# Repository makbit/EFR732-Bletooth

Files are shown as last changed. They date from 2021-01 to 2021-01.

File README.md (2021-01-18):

# EFR732-Bluetooth
EFR732 - is a multi-protocol radio board based on the [EFR32MG1P732F256GM32 @40MHz MCU](https://www.silabs.com/wireless/zigbee/efr32mg1-series-1-socs/device.efr32mg1p732f256gm32) from the SiliconLabs in the 5x5mm QFN32 package. Now this MCU is announced as deprecated. :disappointed:

This MCU supports:
* Bluetooth Smart (BLE),
* ZigBee,
* Thread,
* Proprietary protocols.

Maximum TX Power is: 2.4 GHz @ 19.5 dBm, Antenna in the SMA connector adds +3dBm.
This MCU integrate a 512kB serial flash in the package.

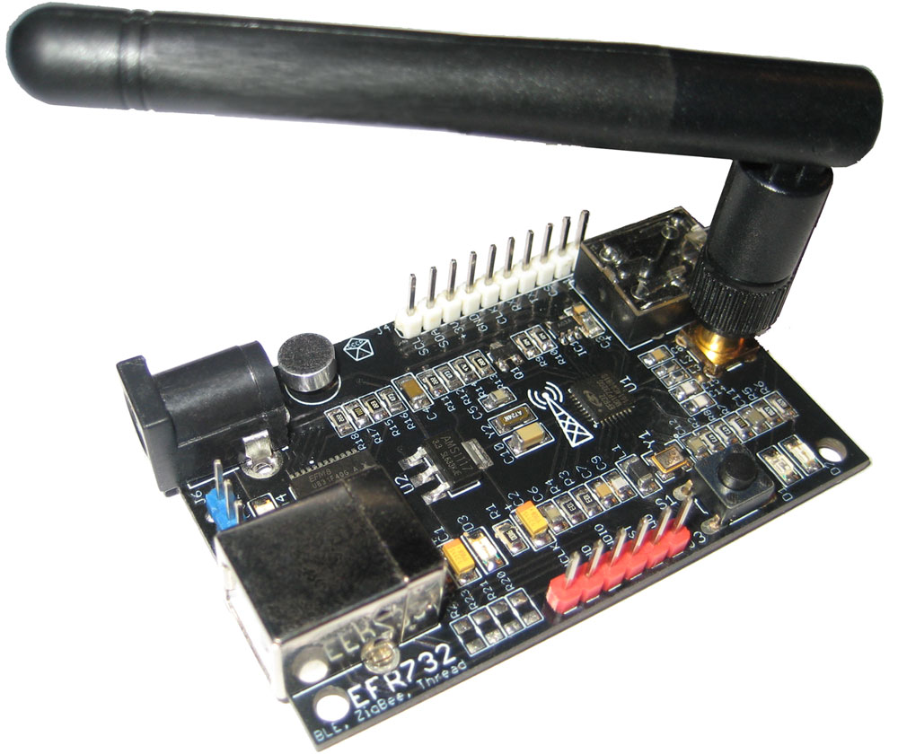
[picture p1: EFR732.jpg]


### Key features:
 - The board has JTAG/SWD pins compatible with the J-Link debug adapter (PF0 - SWCLK, PF1 - SWDIO, PF2 - SWO).
 - The on-board microphone with the amplifier is connected to the MCU ADC port (PB13).
 - The iDAC output is amplified with the LM321 (PB12).
 - There is a USB-to-UART bridge based on the [EFM8UB31F40 MCU](https://www.silabs.com/mcu/8-bit/efm8-universal-bee/device.efm8ub31f40g-qsop24) : P04_TX -> PA1_RX, P05_RX -> PA0_TX. I hope this 8051 MCU can be used as a programmer/debugger someday.
 - Two pins are connected: P03 -> PB11 (clk), P06 -> PD13 (cs). Debug pins are not connected yet.
 - User push-button is connected to PF3.

The [`Hardware`](Hardware) folder contains Eagle CAD 9.0 schematics files. Component library can be found in my repositories.
The board schematics can be found in the[`Hardware/EFR732.png`](Hardware/EFR732.png) file.

### TODO
- [ ] Add firmware folder with examples and some useful stuff.
- [ ] Write USB-to-UART firmware for EFM8.

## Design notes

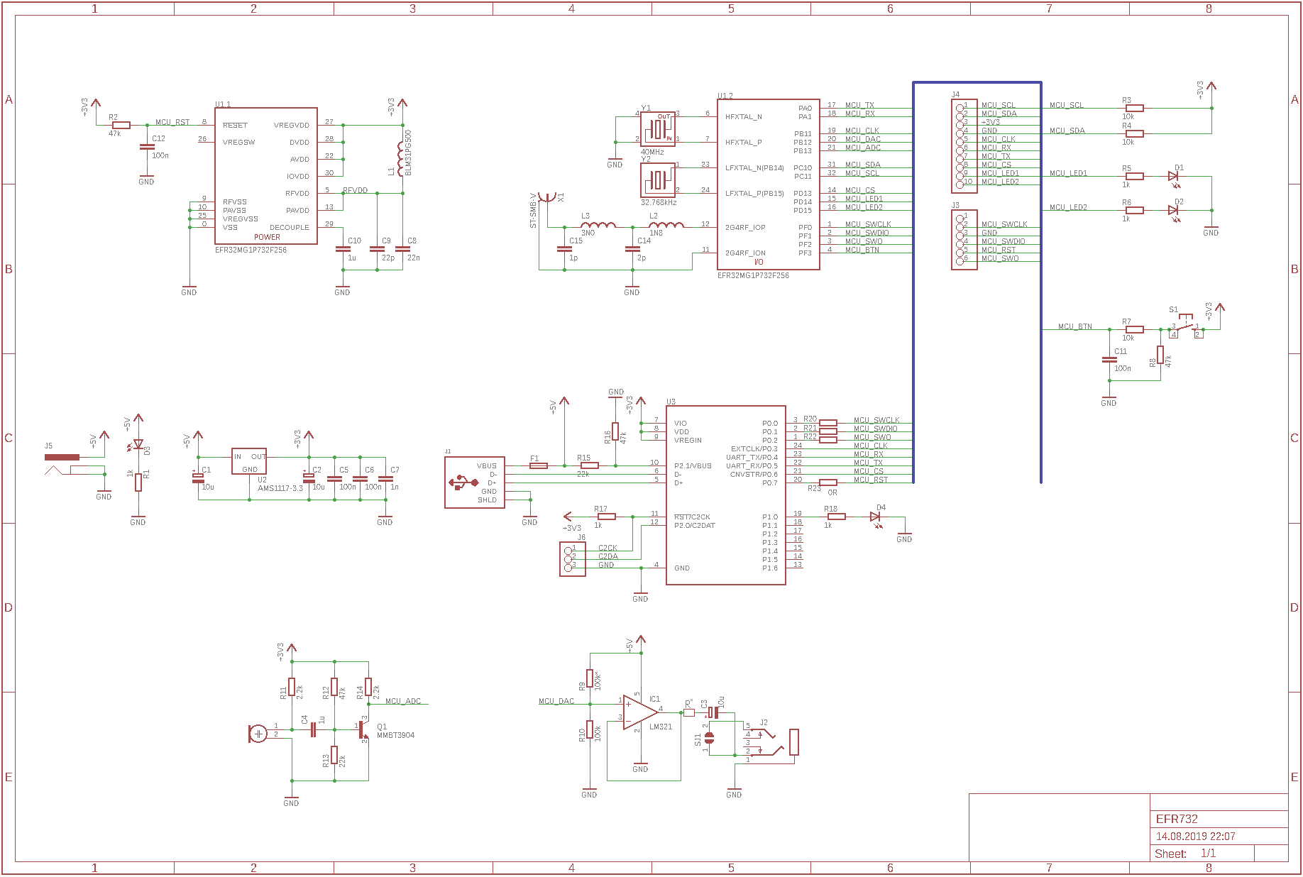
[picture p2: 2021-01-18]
Hardware/EFR732.png

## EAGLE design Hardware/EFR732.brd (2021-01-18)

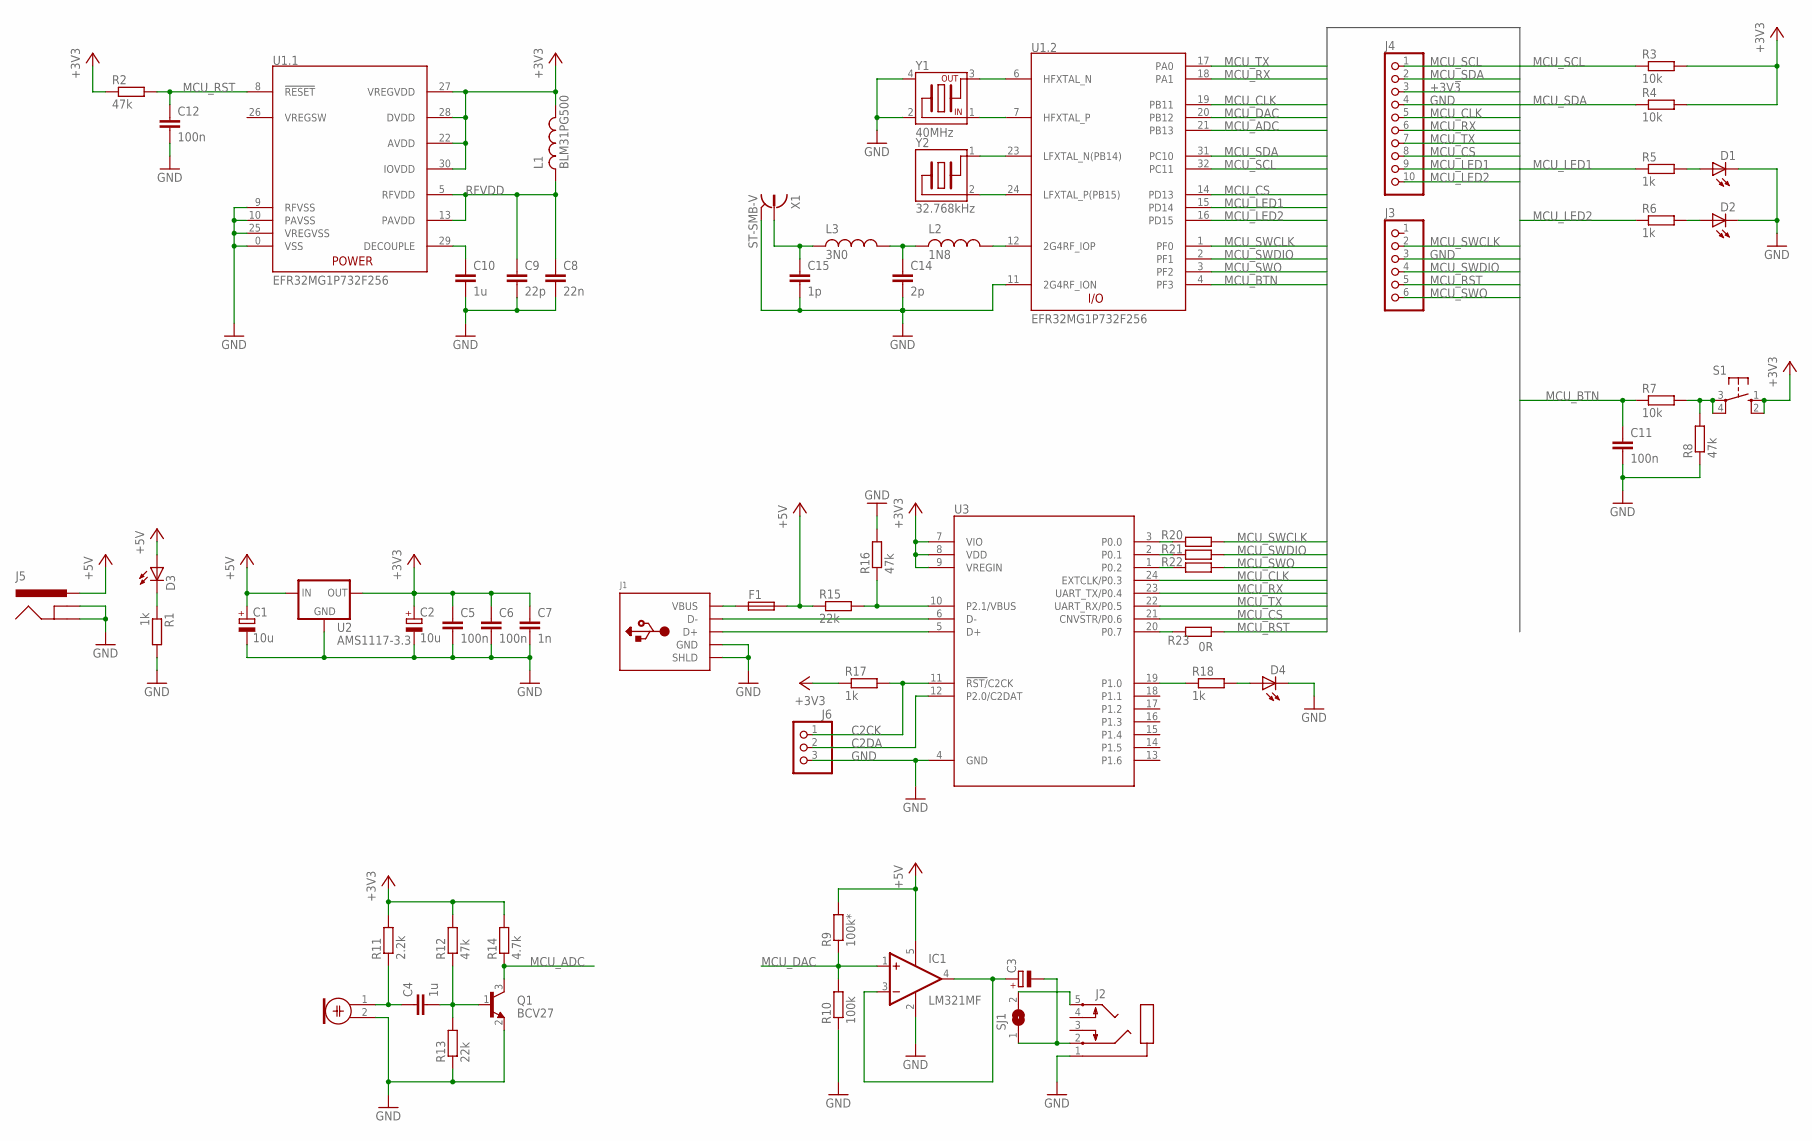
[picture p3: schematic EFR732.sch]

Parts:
C1, C2: 10u; RCL-1206F-POL
C3: CPOL-EU; RCL-1206F-POL
C4, C10: 1u; RCL-1206F
C5, C6, C11, C12: 100n; RCL-0805F
C7: 1n; RCL-0805F
C8: 22n; RCL-0805F
C9: 22p; RCL-0805F
C14: 2p; RCL-0805F
C15: 1p; RCL-0805F
D1, D2, D3, D4: LED1206; LED-1206F
F1: FUSE-NSMF; RCL-1206F
IC1: LM321MF; SOT23-5
J1: USB-TYPE-B; USB-TYPE-B-4P
J2: AUDIO-JACK-3.5MM; AUDIO-PG203J
J3: PINH-1X06
J4: PINH-1X10
J5: POWER_JACK; POWER_JACK_PTH
J6: PINHD-1X3; 1X03
L1: BLM31PG500; RCL-1206F
L2: 1N8; RCL-0603F
L3: 3N0; RCL-0603F
M1: ELECTRET_MICROPHON-WM-62PC/62PK; WM-62PC/62PK
Q1: BCV27; SOT23
R1, R5, R6, R17, R18: 1k; RCL-0805F
R2, R8, R12, R16: 47k; RCL-0805F
R3, R4, R7: 10k; RCL-0805F
R9: 100k*; RCL-0805F
R10: 100k; RCL-0805F
R11: 2.2k; RCL-0805F
R13, R15: 22k; RCL-0805F
R14: 4.7k; RCL-0805F
R20, R21, R22: R-EU0805; RCL-0805F
R23: 0R; RCL-0805F
S1: SWITCH-10-XX; BUTTON-B3F-10XX
SJ1: SJ
U1: EFR32MG1P732F256; QFN32_5X5MM_EFR32MG1
U2: AMS1117-3.3; SOT223
U3: EFM8UB31F40G-QSOP24; QSOP24-3.9X8.65MM
X1: ST-SMB-V
Y1: 40MHz; XTAL-FA-238
Y2: 32.768kHz; XTAL-FC-135

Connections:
+3V3: C2.+, C5.1, C6.1, C7.1, J4.3, L1.2, R2.1, R3.2, R4.2, R11.2, R12.2, R14.2, R17.1, S1.1 (S), S1.2 (S1), U1.22 (AVDD), U1.27 (VREGVDD), U1.28 (DVDD), U1.30 (IOVDD), U2.2 (OUT), U2.4 (OUT), U3.7 (VIO), U3.8 (VDD), U3.9 (VREGIN)
+5V: C1.+, D3.A, F1.2, IC1.5 (V+), J5.PWR, R9.2, R15.1, U2.3 (IN)
C2CK: J6.1, R17.2, U3.11 (!RST/!C2CK)
C2DA: J6.2, U3.12 (P2.0/C2DAT)
GND: C1.-, C2.-, C5.2, C6.2, C7.2, C8.2, C9.2, C10.2, C11.2, C12.2, C14.2, C15.2, D1.C, D2.C, D4.C, IC1.2 (V-), J1.4_GND (GND), J1.M1 (SHLD), J1.M2 (SHLD), J2.1, J3.3, J4.4, J5.GND, J5.GNDBREAK, J6.3, M1.2, Q1.2 (E), R1.2, R8.1, R10.1, R13.1, R16.2, U1.0 (VSS), U1.9 (RFVSS), U1.10 (PAVSS), U1.11 (2G4RF_ION), U1.25 (VREGVSS), U2.1 (GND), U3.4 (GND), X1.2, X1.3 (2), X1.4 (2), X1.5 (2), Y1.2, Y1.4
MCU_ADC: Q1.3 (C), R14.1, U1.21 (PB13)
MCU_BTN: C11.1, R7.1, U1.4 (PF3)
MCU_CLK: J4.5, U1.19 (PB11), U3.24 (EXTCLK/P0.3)
MCU_CS: J4.8, U1.14 (PD13), U3.21 (CNVSTR/P0.6)
MCU_DAC: IC1.1 (+IN), R9.1, R10.2, U1.20 (PB12)
MCU_LED1: J4.9, R5.1, U1.15 (PD14)
MCU_LED2: J4.10, R6.1, U1.16 (PD15)
MCU_RST: C12.1, J3.5, R2.2, R23.2, U1.8 (!RESET)
MCU_RX: J4.6, U1.18 (PA1), U3.23 (UART_TX/P0.4)
MCU_SCL: J4.1, R3.1, U1.32 (PC11)
MCU_SDA: J4.2, R4.1, U1.31 (PC10)
MCU_SWCLK: J3.2, R20.2, U1.1 (PF0)
MCU_SWDIO: J3.4, R21.2, U1.2 (PF1)
MCU_SWO: J3.6, R22.2, U1.3 (PF2)
MCU_TX: J4.7, U1.17 (PA0), U3.22 (UART_RX/P0.5)
unnamed: U1.23 (LFXTAL_N(PB14)), Y2.1 (1.XIN)
unnamed: U1.24 (LFXTAL_P(PB15)), Y2.2 (2.XIN)
unnamed: U1.7 (HFXTAL_P), Y1.1 (X.IN)
unnamed: U1.6 (HFXTAL_N), Y1.3 (X.OUT)
unnamed: F1.1, J1.1_VBUS (VBUS)
unnamed: C14.1, L2.1, L3.2
unnamed: R20.1, U3.3 (P0.0)
unnamed: C15.1, L3.1, X1.1
unnamed: D3.C, R1.1
unnamed: D1.A, R5.2
unnamed: C10.1, U1.29 (DECOUPLE)
unnamed: D2.A, R6.2
unnamed: C3.+, IC1.3 (-IN), IC1.4 (OUT)
unnamed: J2.5, SJ1.2
unnamed: R7.2, R8.2, S1.3, S1.4 (P1)
unnamed: J1.2_DM (D-), U3.6 (D-)
unnamed: J1.3_DP (D+), U3.5 (D+)
unnamed: R21.1, U3.2 (P0.1)
unnamed: R15.2, R16.1, U3.10 (P2.1/VBUS)
unnamed: C4.1, M1.1, R11.1
unnamed: C3.-, J2.2, SJ1.1
unnamed: C4.2, Q1.1 (B), R12.1, R13.2
unnamed: R22.1, U3.1 (P0.2)
unnamed: R18.1, U3.19 (P1.0)
unnamed: D4.A, R18.2
unnamed: R23.1, U3.20 (P0.7)
RFVDD: C8.1, C9.1, L1.1, U1.5 (RFVDD), U1.13 (PAVDD)
RF_IOP: L2.2, U1.12 (2G4RF_IOP)
VREGSW: U1.26 (VREGSW)

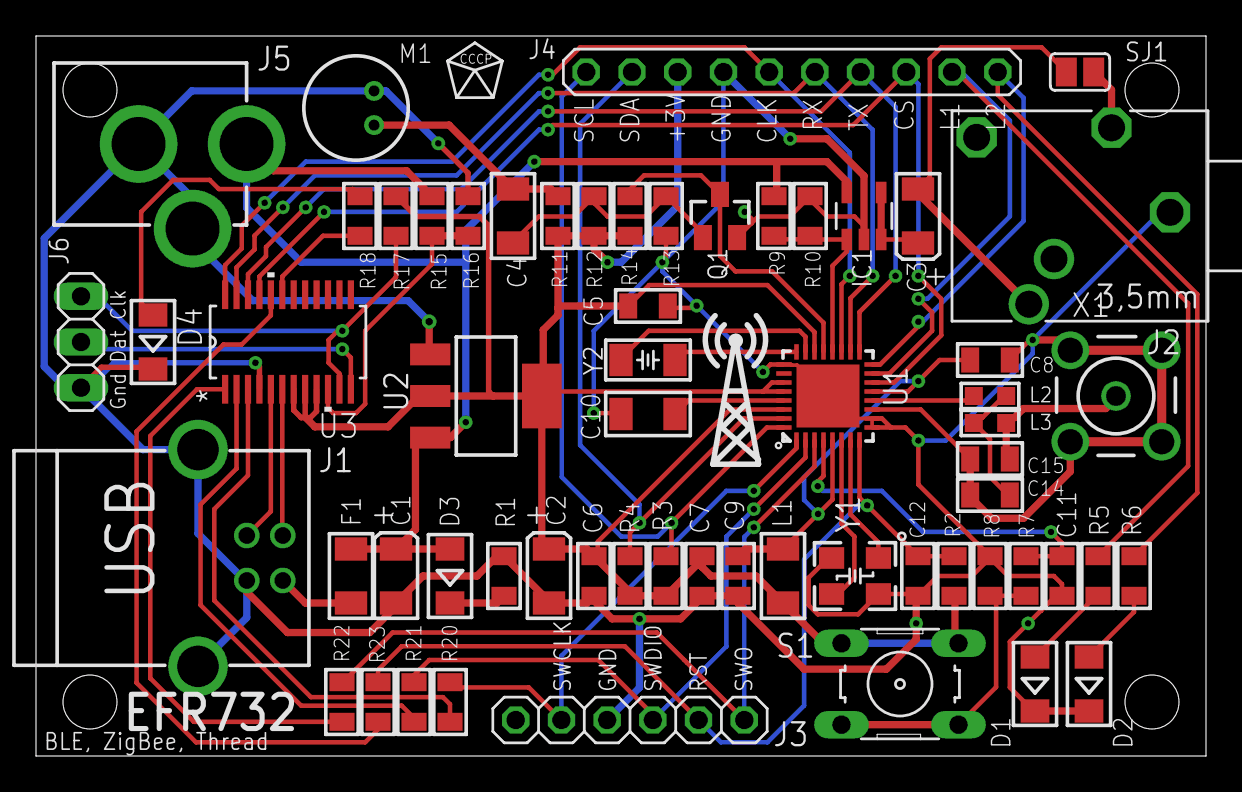
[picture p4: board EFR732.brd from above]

Board: 2 copper layers, 65.0 x 40.0 mm, 61 parts (0 on the bottom side), 48 nets.

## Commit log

2021-01-18 Hardware project files for Eagle CAD 9.0
    [EFR732.brd, EFR732.sch]
2021-01-18 Board image with antenna
2021-01-18 PCB Image with Antenna
